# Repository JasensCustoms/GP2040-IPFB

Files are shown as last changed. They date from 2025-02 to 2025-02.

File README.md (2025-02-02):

<p align="center">
  Jasen's Customs Logo
</p>

The <a href="https://jasenscustoms.com/collections/fight-stick-pcbs/products/integrated-pico-fighting-board-gp2040ce">Integrated Pico Fighting Board</a> is an open source arcade fight stick PCB design made available under the Creative Commons Attribution-Non Commercial Sharealike 4.0 International License. This is a solely **hardware** project that is designed to easily run **unmodified** GP2040-CE firmware. That has always been the intent despite narratives suggesting otherwise.



It was designed to follow the Fighting Game Community Layout Generally Accepted Standard originally pioneered by AkiShop. This design was adopted by Brook for most of their fighting boards at the behest and urging of myself and a few other makers in the space early in Brook's entry to the market. The goal was to make the IPFB a low cost, easy drop-in in replacement for the PS360+ or any Brook Board if a person so chose.

## Design Files

All design files are made using Autodesk EagleCAD and will only be published in that format. Gerbers and Centroids will not be provided. A basic BOM will also be provided. This is to allow hobbyists with some design experience to use their choice of board house to produce their PCBs. There are many to chose from, and it is not our intent to influence your choice. All files are provided as-is without any guarantee of support or help. 

## Sale Channels

Note: The only entity that may sell the Integrated Pico Fighting Board Design is at the link above. If you wish to offer this design commercially, please reach out to [jasenhicks@jasenscustoms.com ](mailto:jasenhicks@jasenscustoms.com). If others are approved to sell the design, they will be listed here. I encourage you to inform me if you see unapproved commercial sale of the IPFB. As of now, I have chosen to stop production of the IPFB. A full discussion can be found on our discord, linked below.

## GPIO Settings 

Main Buttons and Directions:

- GPIO 0: Left
- GPIO 1: Up
- GPIO 2: Down
- GPIO 3: Right
- GPIO 4: HOME (PS)
- GPIO 5: SELECT (SHARE)
- GPIO 6: START
- GPIO 7: Punch 1
- GPIO 8: Punch 2
- GPIO 9: Punch 3
- GPIO 10: Punch 4
- GPIO 11: Kick 1
- GPIO 12: Kick 2
- GPIO 13: Kick 3
- GPIO 14: Kick 4

RGB Data Channel

- GPIO 15: RGB Data

Player LEDS (Version 2.0+ PCB can designate these as other functions as the resistor on the line has been removed)

- GPIO 16: Player 1 LED
- GPIO 17: Player 2 LED
- GPIO 18: Player 3 LED
- GPIO 19: Player 4 LED

Modern Controller Buttons, Turbo Functions

- GPIO 20: Touch Pad Click
- GPIO 21: L3
- GPIO 22: R3
- GPIO 23: TURBO LED (Version 2.0+ PCB can designate this as another function as the resistor on the line has been removed)
- GPIO 28: TURBO KEY

I2C Lines both have been pulled high via resistor (3.3V)

- GPIO 26: SDA
- GPIO 27: SCL

USB Passthrough GPIO

- GPIO 24: DATA PLUS
- GPIO 25: DATA MINUS

## Firmware

No custom firmware is needed or provided for the Integrated Pico Fighting Board. Because the pin definitions are derived from FeralAI's carrier board, firmware for the Pico Fighting Board is expected to be compatible with minimal settings changes. Steps to customize GP2040-CE settings to fully utilize Turbo and Playstation authentication are indicated below.

### Settings
To manually adust the PicoFightingBoard firmware to work perfectly with the IPFB, just adjust these settings.

#### Turbo
- Add on Configuration:
  - Enable turbo
  - Turbo LED Pin 23
  - Save
- Pin Mappings:
  - Set pin 28 to Turbo
  - Save

#### PS5 (or PS4)
- Input Mode Settings
  - Current Input Mode: PS5 (or PS4)
  - Authentication Settings: Host USB
- Boot Input Modes
  - Set B4 to PS5 (or PS4)

#### XBone
- Boot Input Modes
  - Set R1 to XBone

## Support

All files are provided as is and without warranty.

For issues with Integrated Pico Fight Board hardware that was bought and sold via JasensCustoms.com, please reach out via [Jasen's Customs Discord](https://discord.gg/M9E8PFHSCm).

To discuss GP2040-CE firmware including features, issues, or anything else please join the [OpenStick GP2040-CE Discord](https://discord.gg/k2pxhke7q8) or [create a GitHub issue](https://github.com/OpenStickCommunity/GP2040-CE/issues/new).

Hardware change suggestions can be submitted as GitHub issues on this repository, and will be reviewed on a case by case basis by the JasensCustoms.com team. Not all suggestions will be implemented.

## Acknolwedgements

- [RegentOfOrigin](https://github.com/RegentOfOrigin) for helping manage the GitHub
- [wrennnnnn](https://github.com/wrennnnnn). for the initial management and compiling of the FW with the IPFB Config.h file
- [The entire Open Stick Community](https://github.com/OpenStickCommunity) for the GP2040-CE firmware
- Particularly [FeralAI](https://github.com/FeralAI) for the initial work in designing and making the [PicoFightingBoard](https://github.com/FeralAI/PicoFightingBoard) available

Copyright for the Pico Fighting Board is held by FeralAI, 2021.
Copyright for GP2040-CE is held by The Open Stick Community, 2024.

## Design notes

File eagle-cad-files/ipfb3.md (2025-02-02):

EagleCAD files, both Board and Schematic Files for the IPFB 3.0

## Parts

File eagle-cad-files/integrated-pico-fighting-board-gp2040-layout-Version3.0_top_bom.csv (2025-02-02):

Comment | Designator | Footprint | LCSC Part #
Screw Terminals -3.5mm | X8, X9, X10, X11 ,X12 |  | C2997511
JST XH 5 Side | X6 |  | C157991
JST PH 5 Side | X4 |  | C157923
JST PH5 Vertical | X3 |  | C157993
JST PH 3 | X15 |  | C157929
JST PH 4 Side | X1, X2 |  | C157926
SN74LV1T34DBVRG4 | U1 | SOT95P280X145-5N | C1848228
USB-302S | U$2 | USB-302S | C112455
MF-SMDF050 | U$1 | MF-SMDF050 | C210839
MOMENTARY-SWITCH-SPST-SMD-5.2-REDUNDANT | S1 S2 | TACTILE_SWITCH_SMD_5.2MM | C2689410
27 | R9 R10 | R0402 | C25100
22 | R5 R6 | R0805 | C17561
33 | R4 | R0402 | C25105
4.7K | R2 R3 | R0603 | C23162
DNF | R12 | R0402
1K | R11 | R0402 | C11702
330 | R1 R14 | R0603 | C23138
ASE | OSC1 | ASE | C409301
RED | LED2 | CHIP-LED0603 | C2286
2x10 Male | JP2 |  | C5116480
USB B Plug | J6 |  | C498173
W25Q128JVSIQ | IC3 | SOIC127P790X216-8N | C97521
REG1117-3.3 | IC2 | SOT223 | C139396
RP2040-QFN56 | IC1 | RP2040-QFN-56 | C2040
100nF | C3 C4 C5 C6 C7 C8 C9 C11 C12 C15 | C0402K | C1525
1uF | C2 C10 | C0402K | C52923
.01uF | C19 | C0402K | C267411
10uF | C13 C14 | C0402K | C15525
100nF | C1 | C0603K | C14663

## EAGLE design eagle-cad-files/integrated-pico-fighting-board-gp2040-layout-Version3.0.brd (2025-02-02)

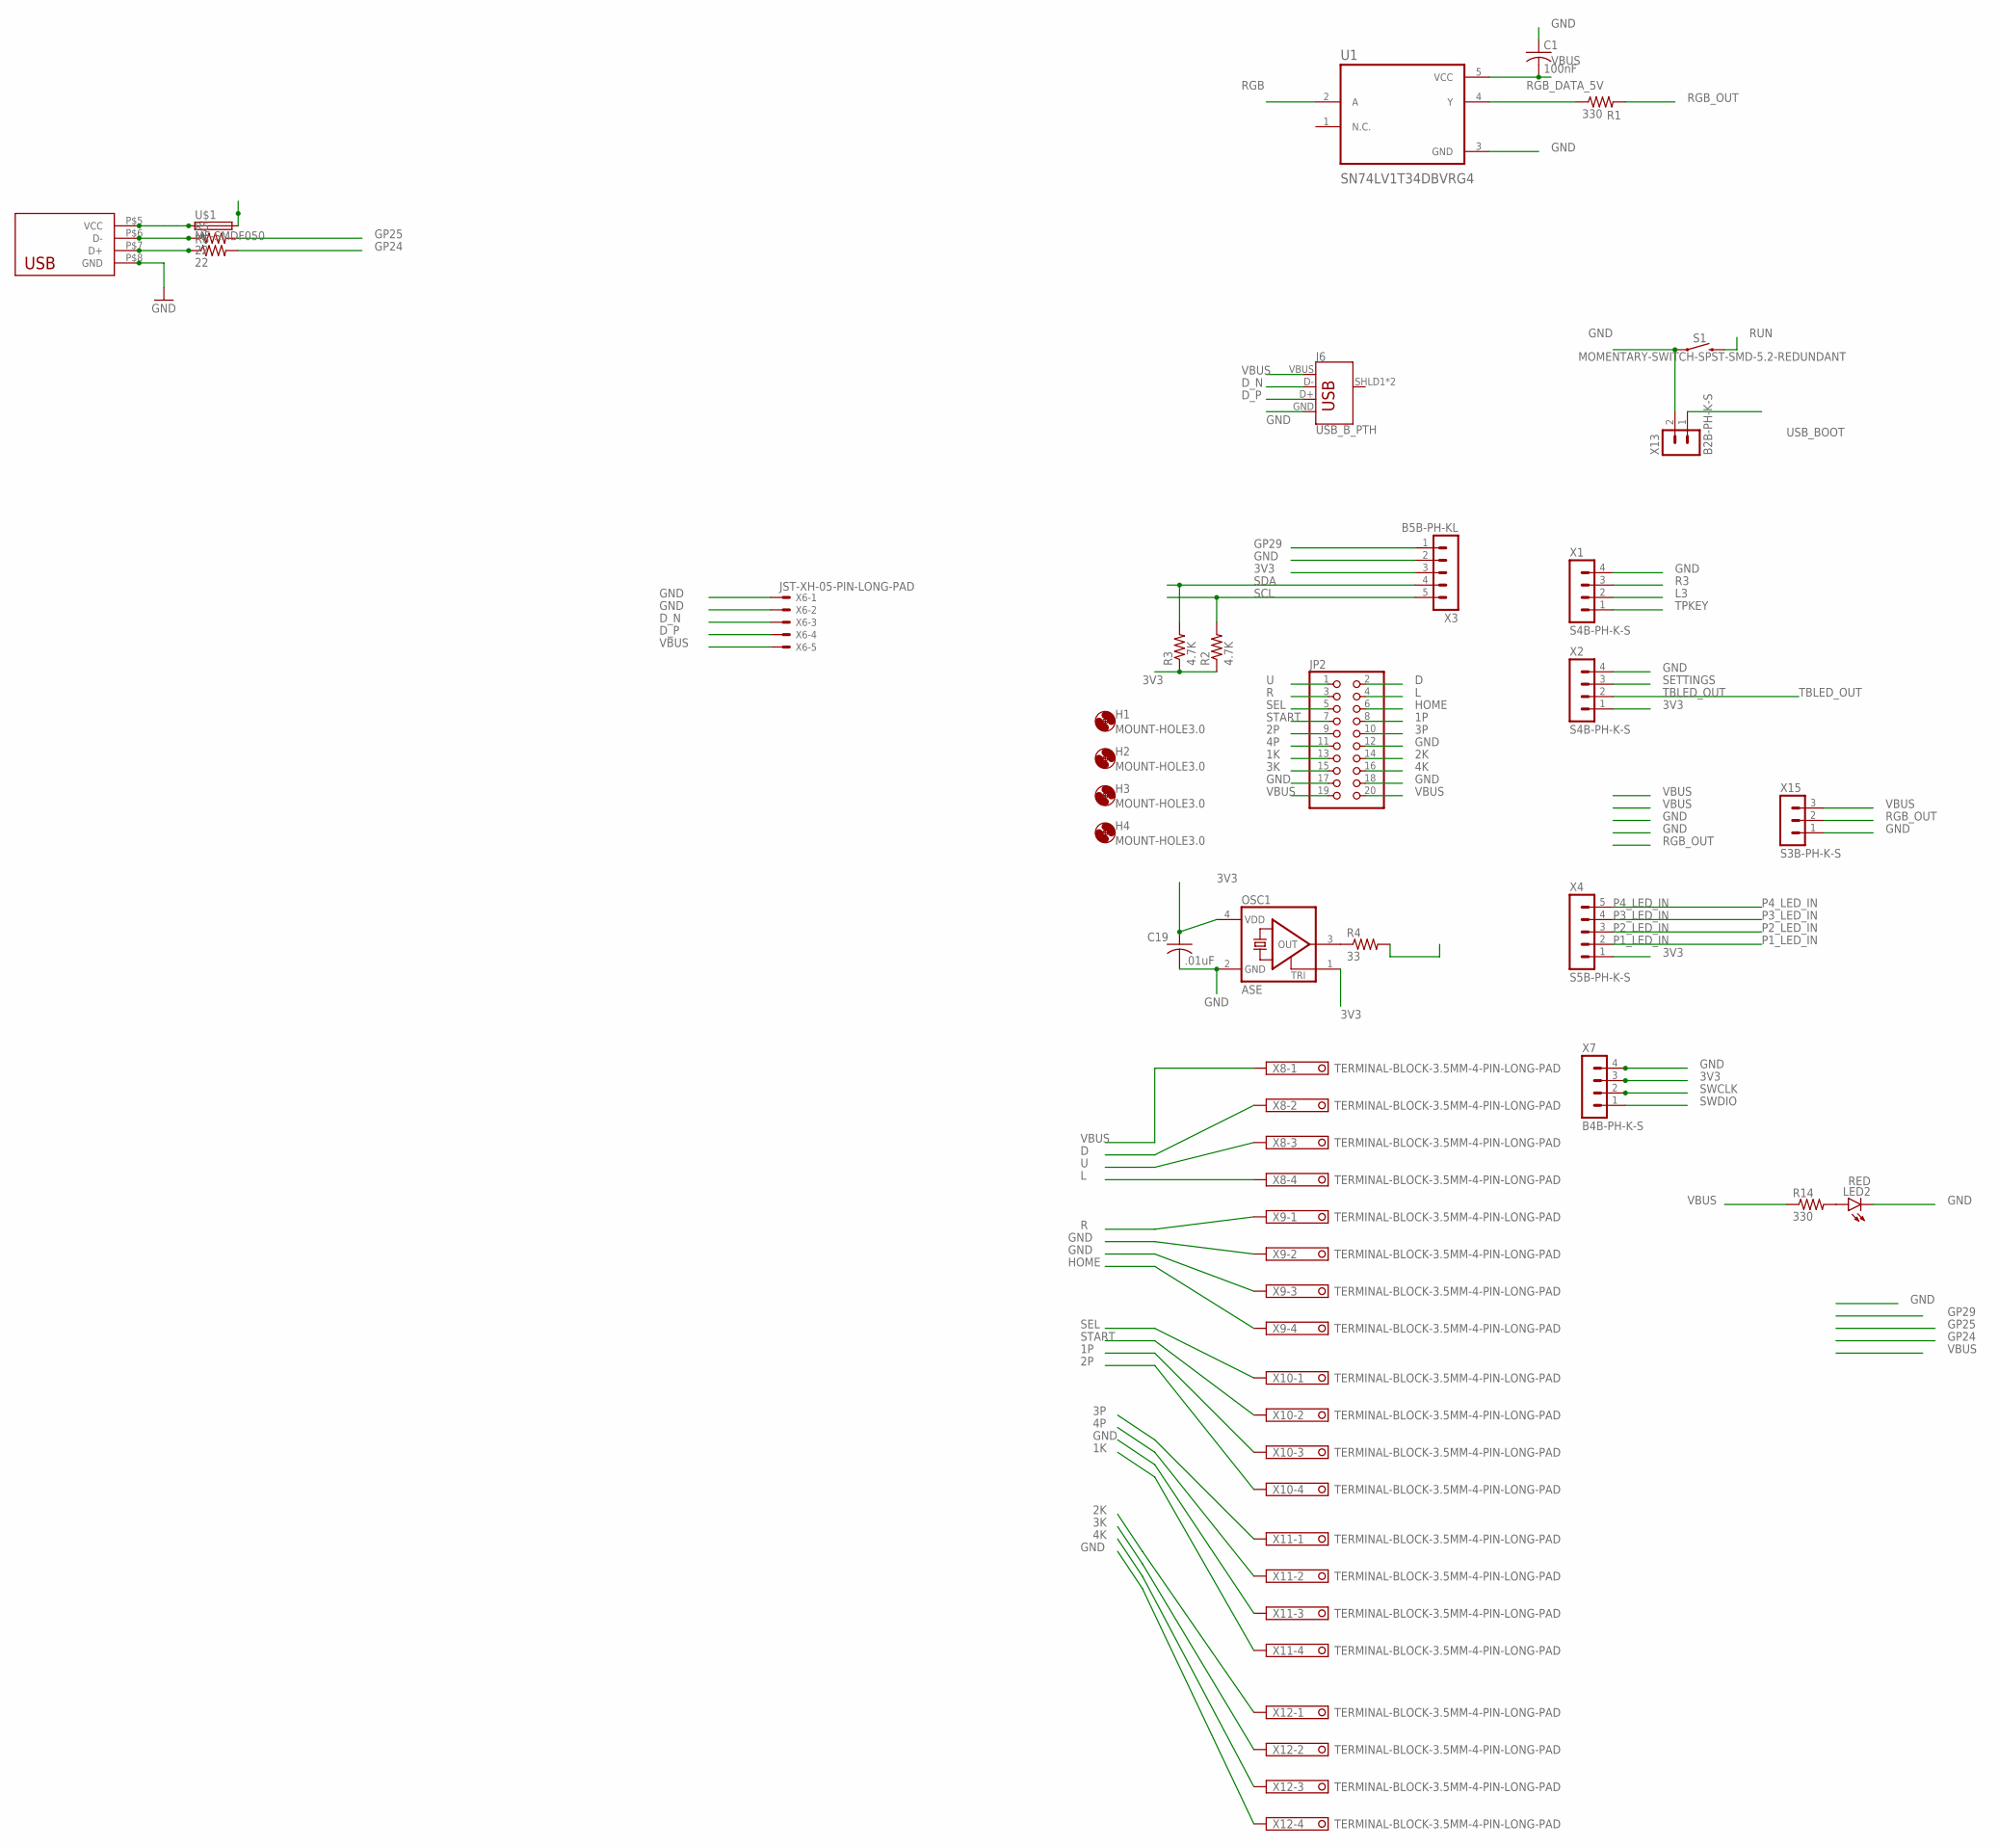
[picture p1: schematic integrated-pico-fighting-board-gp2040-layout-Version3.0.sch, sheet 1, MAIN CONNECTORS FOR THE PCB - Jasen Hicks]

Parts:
C1: 100nF; C0603K
C19: .01uF; C0402K
H1, H2, H3, H4: MOUNT-HOLE3.0; 3,0
J6: USB_B_PTH; USB-B-PTH
JP2: PINHD-2X10; 2X10
LED2: RED; CHIP-LED0603
OSC1: ASE
R1, R14: 330; R0603
R2, R3: 4.7K; R0603
R4: 33; R0402
R5, R6: 22; R0805
S1: MOMENTARY-SWITCH-SPST-SMD-5.2-REDUNDANT; TACTILE_SWITCH_SMD_5.2MM
U1: SN74LV1T34DBVRG4; SOT95P280X145-5N
U$1: MF-SMDF050
U$2: USB-302S
X1, X2: S4B-PH-K-S
X3: B5B-PH-KL; B5B-PH-K-S
X4: S5B-PH-K-S
X6: JST-XH-05-PIN-LONG-PAD; JST-XH-05-PACKAGE-LONG-PAD
X7: B4B-PH-K-S
X8, X9, X10, X11, X12: TERMINAL-BLOCK-3.5MM-4-PIN-LONG-PAD; TERMINAL-BLOCK-4-PIN-3.5MM-LONG-PAD
X13: B2B-PH-K-S
X15: S3B-PH-K-S

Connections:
1K: JP2.13, X11.4; also elsewhere on the board
1P: JP2.8, X10.3; also elsewhere on the board
2K: JP2.14, X12.1; also elsewhere on the board
2P: JP2.9, X10.4; also elsewhere on the board
3K: JP2.15, X12.2; also elsewhere on the board
3P: JP2.10, X11.1; also elsewhere on the board
3V3: C19.1, OSC1.1 (TRI), OSC1.4 (VDD), R2.1, R3.1, X2.1, X3.3, X4.1, X7.3; also elsewhere on the board
4K: JP2.16, X12.3; also elsewhere on the board
4P: JP2.11, X11.2; also elsewhere on the board
D: JP2.2, X8.2; also elsewhere on the board
D_N: J6.D-, X6.3; also elsewhere on the board
D_P: J6.D+, X6.4; also elsewhere on the board
GND: C1.1, C19.2, J6.GND, JP2.12, JP2.17, JP2.18, LED2.C, OSC1.2 (GND), S1.1, S1.2 (1), U1.3 (GND), U$2.P$8 (GND), X1.4, X2.4, X3.2, X6.1, X6.2, X7.4, X9.2, X9.3, X11.3, X12.4, X13.2, X15.1; also elsewhere on the board
GP24: R6.2; also elsewhere on the board
GP25: R5.2; also elsewhere on the board
GP29: X3.1; also elsewhere on the board
HOME: JP2.6, X9.4; also elsewhere on the board
L: JP2.4, X8.4; also elsewhere on the board
L3: X1.2; also elsewhere on the board
unnamed: OSC1.3 (OUT), R4.1
unnamed: LED2.A, R14.2
unnamed: U$1.1, U$2.P$5 (VCC)
unnamed: R5.1, U$2.P$6 (D-)
unnamed: R6.1, U$2.P$7 (D+)
P1_LED_IN: X4.2; also elsewhere on the board
P2_LED_IN: X4.3; also elsewhere on the board
P3_LED_IN: X4.4; also elsewhere on the board
P4_LED_IN: X4.5; also elsewhere on the board
R: JP2.3, X9.1; also elsewhere on the board
R3: X1.3; also elsewhere on the board
RGB: U1.2 (A); also elsewhere on the board
RGB_DATA_5V: R1.1, U1.4 (Y)
RGB_OUT: R1.2, X15.2
RUN: S1.3 (2), S1.4 (2); also elsewhere on the board
SCL: R2.2, X3.5; also elsewhere on the board
SDA: R3.2, X3.4; also elsewhere on the board
SEL: JP2.5, X10.1; also elsewhere on the board
SETTINGS: X2.3; also elsewhere on the board
START: JP2.7, X10.2; also elsewhere on the board
SWCLK: X7.2; also elsewhere on the board
SWDIO: X7.1; also elsewhere on the board
TBLED_OUT: X2.2; also elsewhere on the board
TPKEY: X1.1; also elsewhere on the board
U: JP2.1, X8.3; also elsewhere on the board
USB_BOOT: X13.1; also elsewhere on the board
VBUS: C1.2, J6.VBUS, JP2.19, JP2.20, R14.1, U1.5 (VCC), U$1.2, X6.5, X8.1, X15.3; also elsewhere on the board
XIN: R4.2; also elsewhere on the board

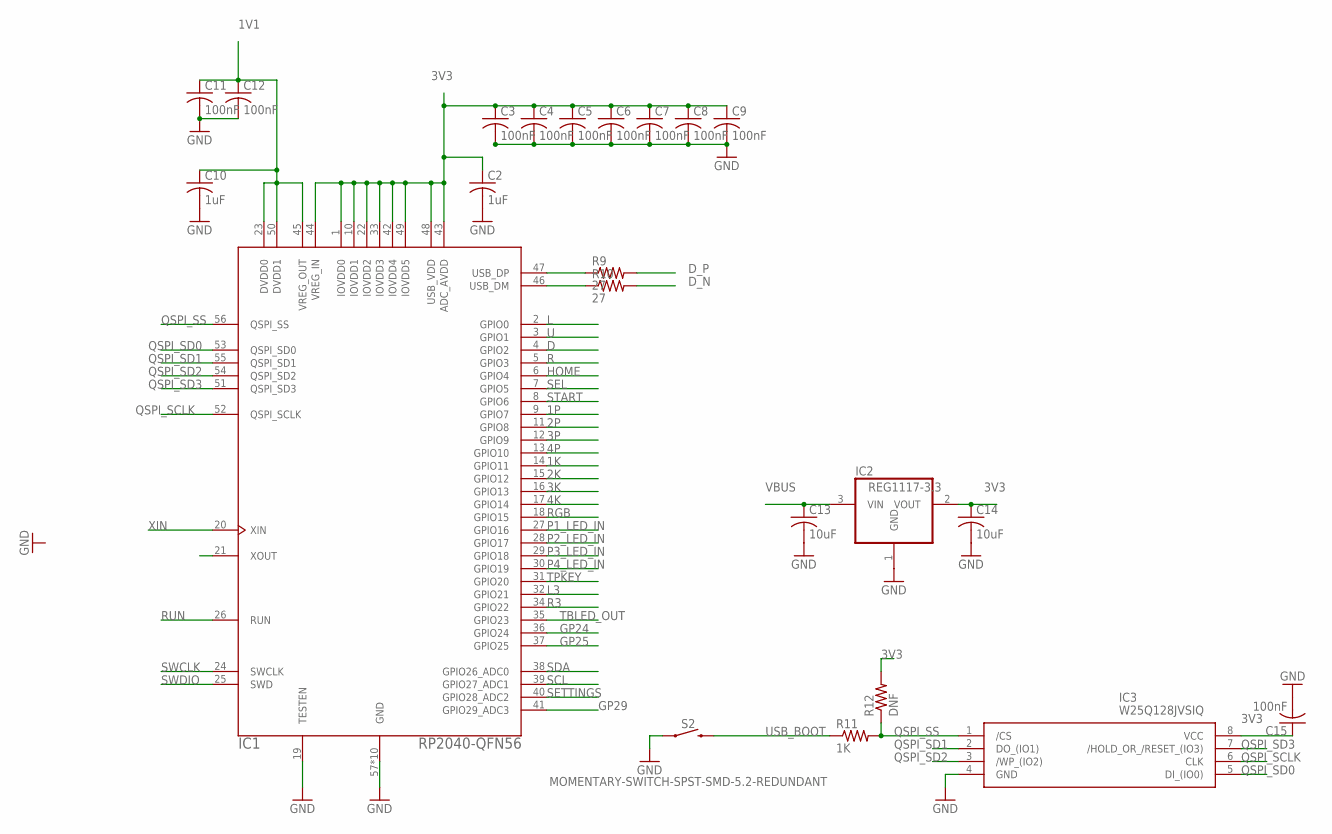
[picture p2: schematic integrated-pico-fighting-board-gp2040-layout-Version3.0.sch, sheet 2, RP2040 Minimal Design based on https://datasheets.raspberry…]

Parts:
C2, C10: 1uF; C0402K
C3, C4, C5, C6, C7, C8, C9, C11, C12, C15: 100nF; C0402K
C13, C14: 10uF; C0402K
IC1: RP2040-QFN56; RP2040-QFN-56
IC2: REG1117-3.3; SOT223
IC3: W25Q128JVSIQ; SOIC127P790X216-8N
R9, R10: 27; R0402
R11: 1K; R0402
R12: DNF; R0402
S2: MOMENTARY-SWITCH-SPST-SMD-5.2-REDUNDANT; TACTILE_SWITCH_SMD_5.2MM

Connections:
1K: IC1.14 (GPIO11); also elsewhere on the board
1P: IC1.9 (GPIO7); also elsewhere on the board
1V1: C10.1, C11.1, C12.1, IC1.23 (DVDD0), IC1.45 (VREG_OUT), IC1.50 (DVDD1)
2K: IC1.15 (GPIO12); also elsewhere on the board
2P: IC1.11 (GPIO8); also elsewhere on the board
3K: IC1.16 (GPIO13); also elsewhere on the board
3P: IC1.12 (GPIO9); also elsewhere on the board
3V3: C2.1, C3.1, C4.1, C5.1, C6.1, C7.1, C8.1, C9.1, C14.1, C15.1, IC1.1 (IOVDD0), IC1.10 (IOVDD1), IC1.22 (IOVDD2), IC1.33 (IOVDD3), IC1.42 (IOVDD4), IC1.43 (ADC_AVDD), IC1.44 (VREG_IN), IC1.48 (USB_VDD), IC1.49 (IOVDD5), IC2.2 (VOUT), IC3.8 (VCC), R12.2; also elsewhere on the board
4K: IC1.17 (GPIO14); also elsewhere on the board
4P: IC1.13 (GPIO10); also elsewhere on the board
D: IC1.4 (GPIO2); also elsewhere on the board
D_N: R10.2; also elsewhere on the board
D_P: R9.2; also elsewhere on the board
GND: C2.2, C3.2, C4.2, C5.2, C6.2, C7.2, C8.2, C9.2, C10.2, C11.2, C12.2, C13.2, C14.2, C15.2, IC1.19 (TESTEN), IC1.57 (GND), IC1.58 (GND), IC1.59 (GND), IC1.60 (GND), IC1.61 (GND), IC1.62 (GND), IC1.63 (GND), IC1.64 (GND), IC1.65 (GND), IC1.66 (GND), IC2.1 (GND), IC3.4 (GND), S2.1, S2.2 (1); also elsewhere on the board
GP24: IC1.36 (GPIO24); also elsewhere on the board
GP25: IC1.37 (GPIO25); also elsewhere on the board
GP29: IC1.41 (GPIO29_ADC3); also elsewhere on the board
HOME: IC1.6 (GPIO4); also elsewhere on the board
L: IC1.2 (GPIO0); also elsewhere on the board
L3: IC1.32 (GPIO21); also elsewhere on the board
unnamed: IC1.47 (USB_DP), R9.1
unnamed: IC1.46 (USB_DM), R10.1
P1_LED_IN: IC1.27 (GPIO16); also elsewhere on the board
P2_LED_IN: IC1.28 (GPIO17); also elsewhere on the board
P3_LED_IN: IC1.29 (GPIO18); also elsewhere on the board
P4_LED_IN: IC1.30 (GPIO19); also elsewhere on the board
QSPI_SCLK: IC1.52 (QSPI_SCLK), IC3.6 (CLK)
QSPI_SD0: IC1.53 (QSPI_SD0), IC3.5 (DI_(IO0))
QSPI_SD1: IC1.55 (QSPI_SD1), IC3.2 (DO_(IO1))
QSPI_SD2: IC1.54 (QSPI_SD2), IC3.3 (/WP_(IO2))
QSPI_SD3: IC1.51 (QSPI_SD3), IC3.7 (/HOLD_OR_/RESET_(IO3))
QSPI_SS: IC1.56 (QSPI_SS), IC3.1 (/CS), R11.2, R12.1
R: IC1.5 (GPIO3); also elsewhere on the board
R3: IC1.34 (GPIO22); also elsewhere on the board
RGB: IC1.18 (GPIO15); also elsewhere on the board
RUN: IC1.26 (RUN); also elsewhere on the board
SCL: IC1.39 (GPIO27_ADC1); also elsewhere on the board
SDA: IC1.38 (GPIO26_ADC0); also elsewhere on the board
SEL: IC1.7 (GPIO5); also elsewhere on the board
SETTINGS: IC1.40 (GPIO28_ADC2); also elsewhere on the board
START: IC1.8 (GPIO6); also elsewhere on the board
SWCLK: IC1.24 (SWCLK); also elsewhere on the board
SWDIO: IC1.25 (SWD); also elsewhere on the board
TBLED_OUT: IC1.35 (GPIO23); also elsewhere on the board
TPKEY: IC1.31 (GPIO20); also elsewhere on the board
U: IC1.3 (GPIO1); also elsewhere on the board
USB_BOOT: R11.1, S2.3 (2), S2.4 (2); also elsewhere on the board
VBUS: C13.1, IC2.3 (VIN); also elsewhere on the board
XIN: IC1.20 (XIN); also elsewhere on the board

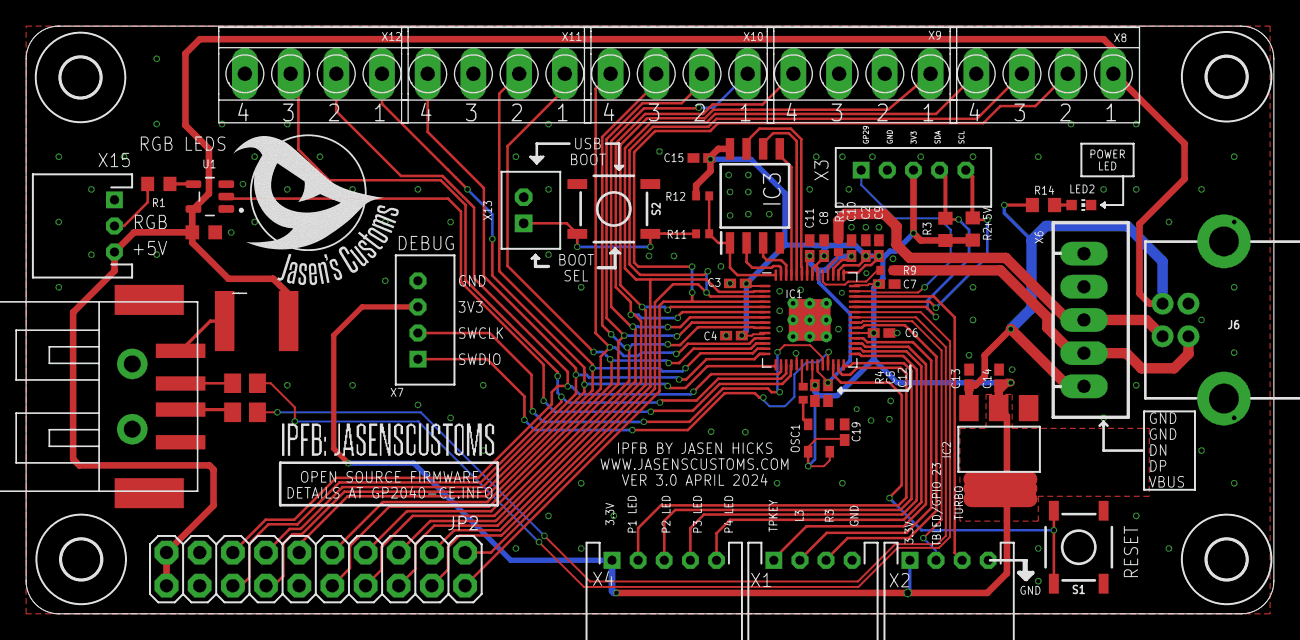
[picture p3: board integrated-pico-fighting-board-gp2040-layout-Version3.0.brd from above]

Board: 2 copper layers, 95.5 x 45.0 mm, 56 parts (0 on the bottom side), 56 nets.

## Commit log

2024-08-25 Integrated Pico Fighting Board config & README
2024-10-10 Remove unnecessary config options from BoardConfig

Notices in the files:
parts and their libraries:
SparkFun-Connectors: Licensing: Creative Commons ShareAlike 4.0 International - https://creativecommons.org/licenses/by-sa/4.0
